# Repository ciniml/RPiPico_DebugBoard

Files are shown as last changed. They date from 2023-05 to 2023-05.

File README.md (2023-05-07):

# Raspberry Pi Pico Debug Board

## 概要

Raspberry Pi Pico用のデバッグ用ボード。

ブレッドボードを使うほどでもないが、デバッガはつなぎたい もしくはPicoprobeのデバッグ・ユニットとして使いたい場合に便利なように配線を引き出すためのボードです。

回路図

[回路図(PDF)](./RPiPico_SimpleBoard.pdf)

基板表

基板裏

## 特徴

* リセット・スイッチ
* Picoprobe用SWD + UART TX/RXコネクタ
* デバッガ接続用ポゴピン実装スルーホール
* 全信号2列引き出し
  * 信号引き出しつつ、ロジックアナライザを接続可能

## 使用例

### RPi Picoを2枚つかったSWDデバッグ

上側のデバッグ基板のファームウェアとして [`rust-dap`](https://github.com/ciniml/rust-dap) を書き込み。下側のRaspberry Pi PicoにLチカファームウェアをデバッガ経由で書き込んでデバッグ中

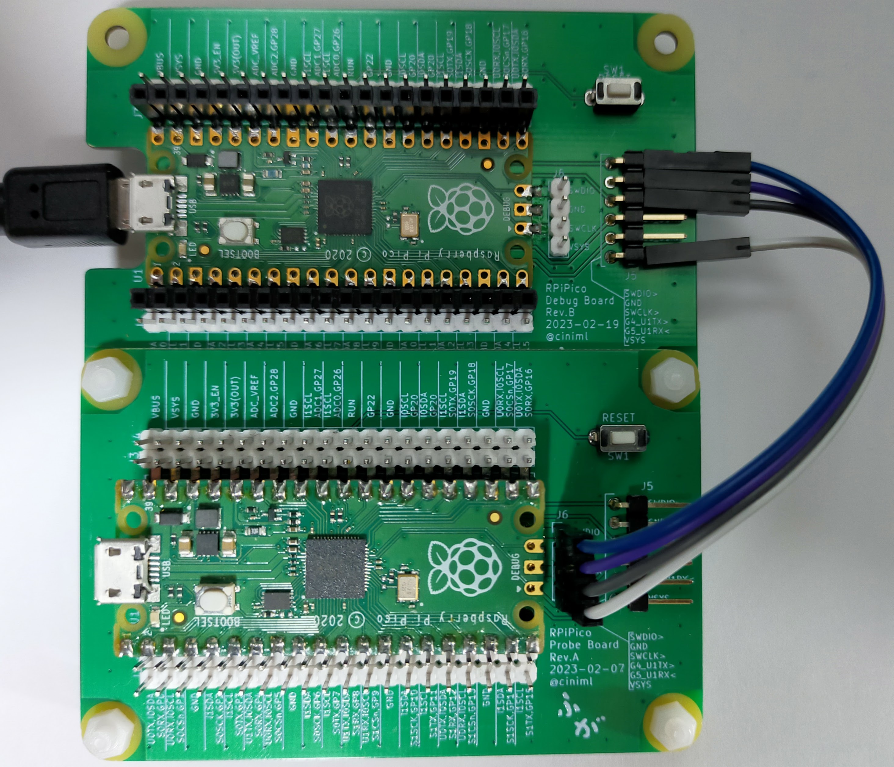
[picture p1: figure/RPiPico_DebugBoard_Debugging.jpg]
RPi Picoを2枚つかったSWDデバッグ


## ライセンス

### 基板本体
CC BY 4.0
<br />This work is licensed under a <a rel="license" href="http://creativecommons.org/licenses/by/4.0/">Creative Commons Attribution 4.0 International License</a>.

### ライブラリ (local.kicad_sym, local.pretty以下)

一部のコンポーネントがKiCad標準のコンポーネントを改変したものであるため、そのライセンス (CC BY-SA 4.0) が適用される

また、Raspberry Pi Picoの3Dモデルも、CC BY-SA 4.0に基いて配布されているので同様である。
https://www.raspberrypi.com/documentation/microcontrollers/raspberry-pi-pico.html

CC BY-SA 4.0
<br />This work is licensed under a <a rel="license" href="http://creativecommons.org/licenses/by-sa/4.0/">Creative Commons Attribution-ShareAlike 4.0 International License</a>.

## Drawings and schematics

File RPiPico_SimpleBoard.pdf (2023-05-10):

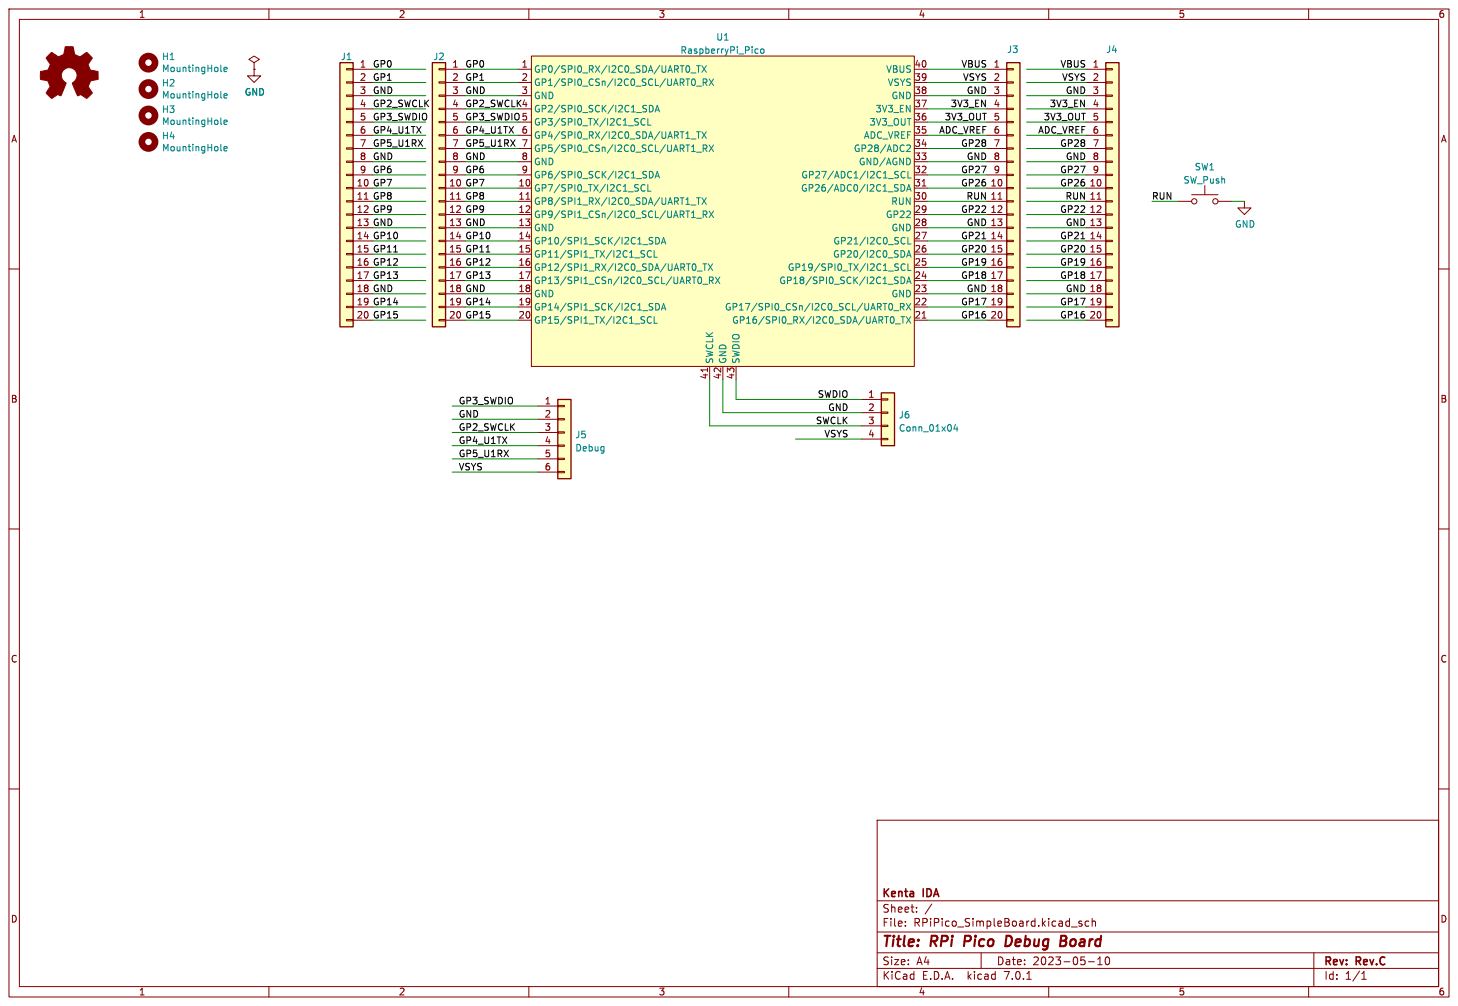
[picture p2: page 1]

Id: 1/1 Title: RPi Pico Debug Board

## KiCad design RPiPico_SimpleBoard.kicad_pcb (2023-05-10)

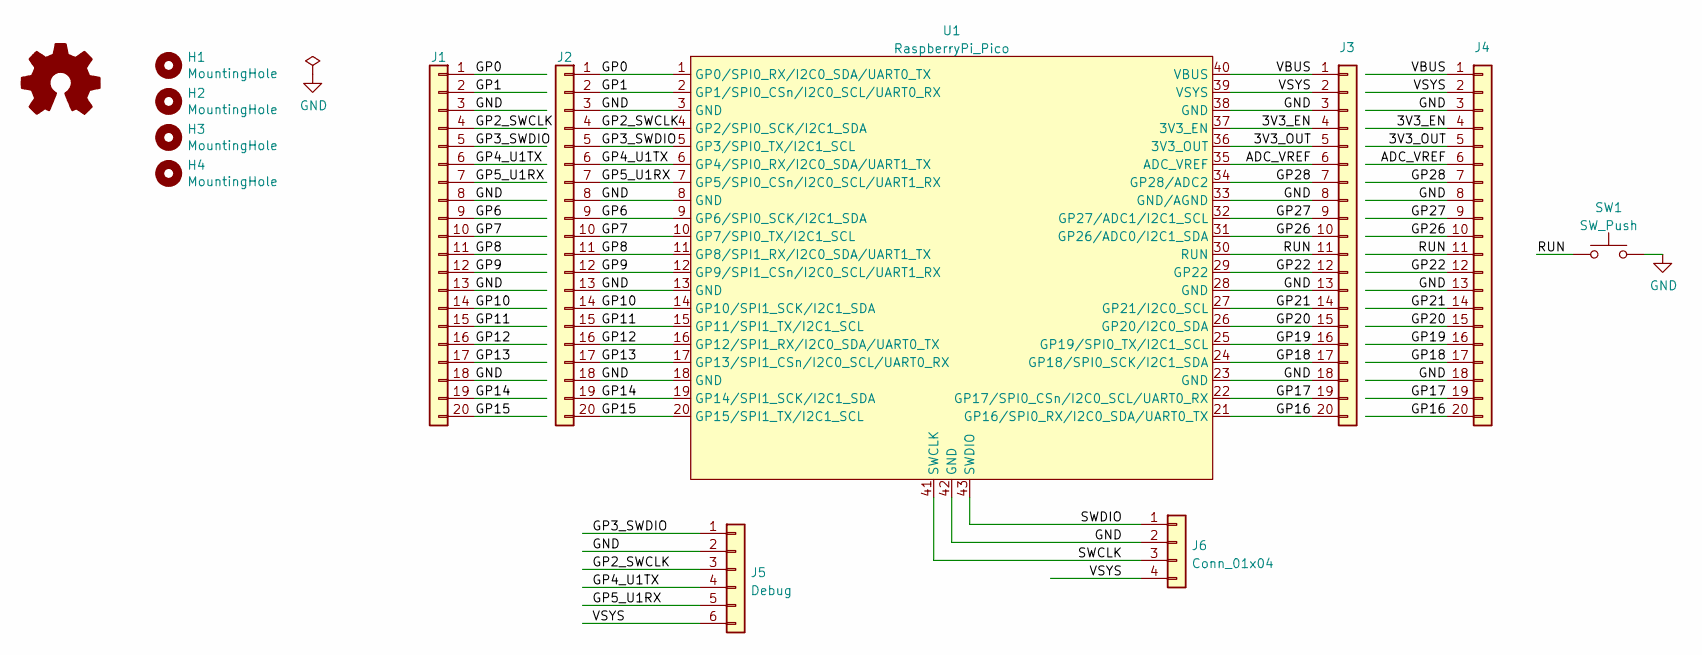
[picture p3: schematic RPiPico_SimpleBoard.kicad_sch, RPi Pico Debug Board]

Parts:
H1, H2, H3, H4: MountingHole; MountingHole_3.2mm_M3
J1, J4: Conn_01x20; PinHeader_1x20_P2.54mm_Vertical_Narrow
J2, J3: Conn_01x20; PinSocket_1x20_P2.54mm_Vertical_Narrow
J5: Debug; PinHeader_1x06_P2.54mm_Horizontal_Narrow
J6: Conn_01x04; PinHeader_1x04_P2.54mm_Vertical
LOGO1: Logo_Open_Hardware_Small; logo
SW1: SW_Push; TVBP06-BN043XX-B
U1: RaspberryPi_Pico; Raspberry_Pi_Pico_TH_SMD_SWD

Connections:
/3V3_EN: J3.4, J4.4, U1.37 (3V3_EN)
/3V3_OUT: J3.5, J4.5, U1.36 (3V3_OUT)
/ADC_VREF: J3.6, J4.6, U1.35 (ADC_VREF)
/GP0: J1.1, J2.1, U1.1 (GP0/SPI0_RX/I2C0_SDA/UART0_TX)
/GP1: J1.2, J2.2, U1.2 (GP1/SPI0_CSn/I2C0_SCL/UART0_RX)
/GP2_SWCLK: J1.4, J2.4, J5.3, U1.4 (GP2/SPI0_SCK/I2C1_SDA)
/GP3_SWDIO: J1.5, J2.5, J5.1, U1.5 (GP3/SPI0_TX/I2C1_SCL)
/GP4_U1TX: J1.6, J2.6, J5.4, U1.6 (GP4/SPI0_RX/I2C0_SDA/UART1_TX)
/GP5_U1RX: J1.7, J2.7, J5.5, U1.7 (GP5/SPI0_CSn/I2C0_SCL/UART1_RX)
/GP6: J1.9, J2.9, U1.9 (GP6/SPI0_SCK/I2C1_SDA)
/GP7: J1.10, J2.10, U1.10 (GP7/SPI0_TX/I2C1_SCL)
/GP8: J1.11, J2.11, U1.11 (GP8/SPI1_RX/I2C0_SDA/UART1_TX)
/GP9: J1.12, J2.12, U1.12 (GP9/SPI1_CSn/I2C0_SCL/UART1_RX)
/GP10: J1.14, J2.14, U1.14 (GP10/SPI1_SCK/I2C1_SDA)
/GP11: J1.15, J2.15, U1.15 (GP11/SPI1_TX/I2C1_SCL)
/GP12: J1.16, J2.16, U1.16 (GP12/SPI1_RX/I2C0_SDA/UART0_TX)
/GP13: J1.17, J2.17, U1.17 (GP13/SPI1_CSn/I2C0_SCL/UART0_RX)
/GP14: J1.19, J2.19, U1.19 (GP14/SPI1_SCK/I2C1_SDA)
/GP15: J1.20, J2.20, U1.20 (GP15/SPI1_TX/I2C1_SCL)
/GP16: J3.20, J4.20, U1.21 (GP16/SPI0_RX/I2C0_SDA/UART0_TX)
/GP17: J3.19, J4.19, U1.22 (GP17/SPI0_CSn/I2C0_SCL/UART0_RX)
/GP18: J3.17, J4.17, U1.24 (GP18/SPI0_SCK/I2C1_SDA)
/GP19: J3.16, J4.16, U1.25 (GP19/SPI0_TX/I2C1_SCL)
/GP20: J3.15, J4.15, U1.26 (GP20/I2C0_SDA)
/GP21: J3.14, J4.14, U1.27 (GP21/I2C0_SCL)
/GP22: J3.12, J4.12, U1.29 (GP22)
/GP26: J3.10, J4.10, U1.31 (GP26/ADC0/I2C1_SDA)
/GP27: J3.9, J4.9, U1.32 (GP27/ADC1/I2C1_SCL)
/GP28: J3.7, J4.7, U1.34 (GP28/ADC2)
/RUN: J3.11, J4.11, SW1.1, U1.30 (RUN)
/SWCLK: J6.3, U1.41 (SWCLK)
/SWDIO: J6.1, U1.43 (SWDIO)
/VBUS: J3.1, J4.1, U1.40 (VBUS)
/VSYS: J3.2, J4.2, J5.6, J6.4, U1.39 (VSYS)
GND: J1.3, J1.8, J1.13, J1.18, J2.3, J2.8, J2.13, J2.18, J3.3, J3.8, J3.13, J3.18, J4.3, J4.8, J4.13, J4.18, J5.2, J6.2, SW1.2, U1.3 (GND), U1.8 (GND), U1.13 (GND), U1.18 (GND), U1.23 (GND), U1.28 (GND), U1.33 (GND/AGND), U1.38 (GND), U1.42 (GND)

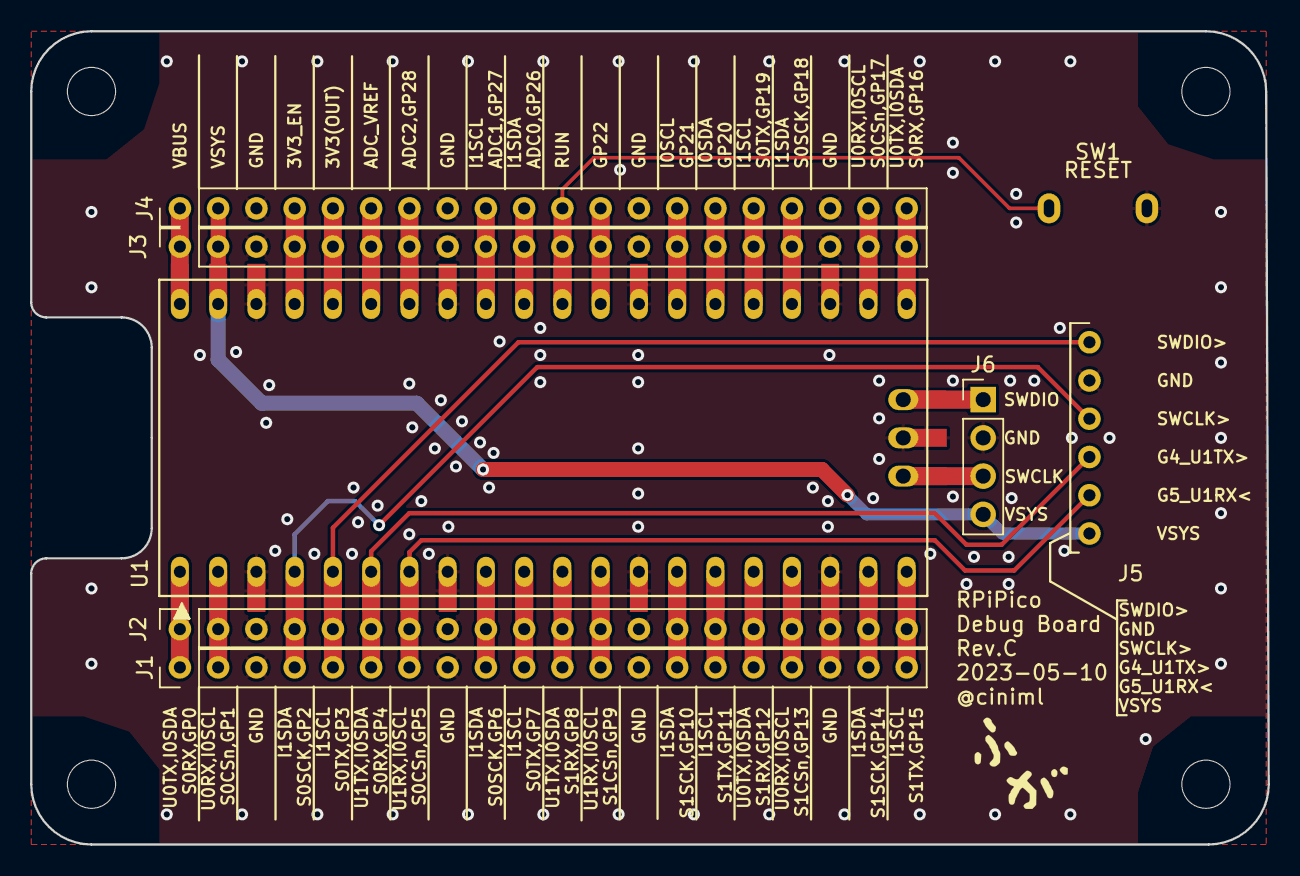
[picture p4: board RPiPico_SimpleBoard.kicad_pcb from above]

Board: 2 copper layers, 82.2 x 54.0 mm, 13 parts (0 on the bottom side), 35 nets.

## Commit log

2023-02-19 Fix outline not to conflict with USB cables.
    [RPiPico_SimpleBoard.gbl, RPiPico_SimpleBoard.gbo, RPiPico_SimpleBoard.gbp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]
2023-05-09 fix some silk prints
    (GP5) U0RX -> U1RX
    (GP26) I1SCL -> I1SDA
    (GP21) GP20 -> GP21
    [RPiPico_SimpleBoard.kicad_pcb]
